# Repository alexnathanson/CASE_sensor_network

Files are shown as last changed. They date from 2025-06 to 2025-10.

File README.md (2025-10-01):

# CASE_sensor_network

https://www.adafruit.com/product/2857

## System Design

Temperature and humidity sensors running on 8 identically configured Raspberry Pi Zero W 2 devices. Each device:
* takes readings every 5 minutes
* stores data locally
* makes data available to other devices on the network through APIs
	* host name is pi*.local where * is a number 1-8
	* Port 5000
	* API endpoints: /api/files, /api/disk, /api/data?date=YYYY-MM-DD

A Windows laptop
* backs up data from each RPi
* collects sensors data from AC
* post aggregated data to cloud database

## Network

When on network, log in to router via a browser with http://tplinkeap.net/ <Br>
See Google Doc for log info.

## Troubleshooting

To find RPi IPs, log in to WAP via browser

## To do

remote access or posting... git?
pscp files to... somewhere?

quality/ health check
* check files exist
* check file sizes
* spot check amount of rows and data validation

fix airtable bug
callibration

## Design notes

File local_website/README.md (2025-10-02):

# Local Website

This directory is for the local website. It will only work on the same local network as the sensors. To run the external website - which pulls less frequent, lower resolution from airtable - see 'external website directory'.

This is a front-end JS only site, the pulls data from the APIs running on the Raspberry Pis.

To run:
* Navigate to the "local_website" directory and run `python -m http.server 8888`
* In a browser, go to http://localhost:8888

## Plots

4 plots
* tempF (ind & abg)
* tempC (ind & abg)
* humidityF (ind & avg)
* Power

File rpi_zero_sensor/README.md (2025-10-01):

# Sensor Network

All RPis should be running:
* dashboard.service

The devices running temperature/ humidity sensors should be running:
* sht31d_logger.service

The device running Kasa should run:
* kasa_logger.service

The device running Airtable (the Kasa rpi in most cases):
* airtable_live.service
* airtable_status.service

Logger collects the data and stores it as a CSV. Dashboard makes the data available via an API. Airtable updates the cloud database.

Note that it is crucial that the host name of each Pi is unique and follows the naming convention. Also, the config file should be updated with the correct number. This should be done automatically if using the installation script. The kasa device is named kasa and the value entered into the config file should be 'kasa'.

Also, each device has a bash script the runs around midnight which pulls the most recent version of the code base from Git.

### Calibration

Calibration values for all sensors is found in the calibration.json file. Updating this file will update the calibration configuration for all sensors. The calibration offset value is applied to the Celsius reading.

## Installation

See <a href='https://github.com/alexnathanson/CASE_sensor_network/blob/main/rpi_zero_sensor/installation.md'>installation doc</a>.

## Dashboards and APIs

### Local Dashboard and APIs

Within the local network (CASE_sensor_network) data from each device can be accessed via their dashboard and APIs. 
All RPi sensors use the same naming convention: pi + #1-8 + .local i.e. pi1.local. The Kasa device can be found at kasa.local.

All APIs and dashboards are available on port 5000

* A dataviz of today's data is available at root: http://pi1.local:5000
* A list of files stored on the device (in json) is available at `api/files`: http://pi1.local:5000/api/files
* To download a specific csv file, use the `api/data` endpoint with the date argument `?date=YYYY-MM-DD`: http://pi1.local:5000/api/data?date=2025-04-6
* To get most recent data (json), use the `api/data` endpoint with the date argument set to now `?date=now`: http://pi1.local:5000/api/data?date=now
* To check disk usage (json), use the `/api/disk` endpoint: http://pi1.local:5000/api/disk

### Local Network Dashboard
When on the local network, live data from all devices can be seen by running the website found in the 'local_website' directory.
* https://github.com/alexnathanson/CASE_sensor_network/blob/main/local%20website/README.md

### External Dashboard

Outside of the local network, data can be check via the Airtable API.

## Airtable

Only 1 RPi in the network updates the airtable. With a free account, we're limited to 1000 API calls a month (~33 calls/ day). 

When both scripts start, they retrieve record IDs (9 calls). Then it updates data as a batch, to minimize calls. The live script makes 1 update every 2 hours, for a total of 21 calls/day. The status script makes 1 update a day, for a total of 9 calls/ day. This requires a combined 30 API calls/ day, for ~930 calls/ month. With a paid account, the resolution can be increased if necessary.

## Troubleshooting

### Status
`sudo systemctl status sht31d_logger.service`

### Logs
`journalctl -u sht31d_logger.service -f`

Stop (temporary) or disable (doesn't start on boot) Service<br>
`sudo systemctl stop sht31d_logger.service`<br>
`sudo systemctl disable sht31d_logger.service`

### Disk Space

Once everything is installed, a 32GB microSD card starts at about 25% full. Check the disk status via the API.

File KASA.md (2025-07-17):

# Kasa

There are 4 Kasa smart plugs in use.

Model: KP125M<br>
Max Load: 15A 1800W

## Setup
You must use the Kasa app to set up the devices and connect them to the network. This requires an account, which is tied to the Kasa username and password. These can be found in the Login & Credentials doc.

In the unlikely event that you need to make changes to the device, you can perform a factory reset and complete the setup instructions on the app. <bold>If you do this, you must update the .env file (and the L&C Google Doc) with the updated credentials.</bold> This file is located in the rpi_zero_sensor directory of each device. You must update all of them.

When setting up a Kasa plug:
* Be sure to use the correct unique name. Devices are named kasa1 to kasa4.
* Make sure they are on the correct wifi network.
* Once set up, in the Kasa app, make sure the default state is set to on.

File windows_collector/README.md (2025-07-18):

# Windows Installation

This scripts is intended to run a local Windows machine to backup data from all sensors.

This is done with the rpi_data_collector.py script.

The best way to automatically run the script is with the Windows Task Scheduler.

Additionally, the local website should be running the this laptop. See <a href='https://github.com/alexnathanson/CASE_sensor_network/tree/main/local_website'>https://github.com/alexnathanson/CASE_sensor_network/tree/main/local_website</a>.

The local website should also be running on this device. Use port 8888 when using Windows Task Scheduler.

## Installation

1) Clone the repository: `git clone https://github.com/alexnathanson/CASE_sensor_network`
2) Create the virtual environment: `python -m venv venv`
3) Activate the virtual environment: `venv\Scripts\activate`
4) Navigate to the windows_collector directory and install requirements:
`pip install -r requirements.txt`
5) Schedule tasks to run via Windows Task Scheduler.

### Windows Task Scheduler
Python scripts can be run via Windows Task Scheduler

General
* Name the task
* Set to run whether user is logged in or not
Triggers
* Set to daily. Around 1am is a good time, because all the sensors will have completed their daily reboot by then.
Actions
* set the script to the python.exe file in your venv
* add the script's full filepath as an argument
* start in specifies the directory it starts from
Conditions
* don't depend on the network connect...
Settings
* run task as soon as possible

## Alternative Automation Method

You can also run the script with NSSM, but this isn't fully tested and is more meant for services not running once a day like this program.

* Download NSSM
* Place nssm.exe in nssm folder in programs directory
* add to environment paths
* open temrinal as admin
	* `nssm install rpi_data_collector`
	* path is path to python.exe in venv
	* startup directory is windows_collector\
	* arg is path to rpi_data_collector.py
	* start service with `nssm start rpi_data_collector`
	* check status with task manager (might just show up as python) or `nssm status rpi_data_collector`

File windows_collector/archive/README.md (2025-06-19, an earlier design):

# Directory for archiving copies of data from sensors

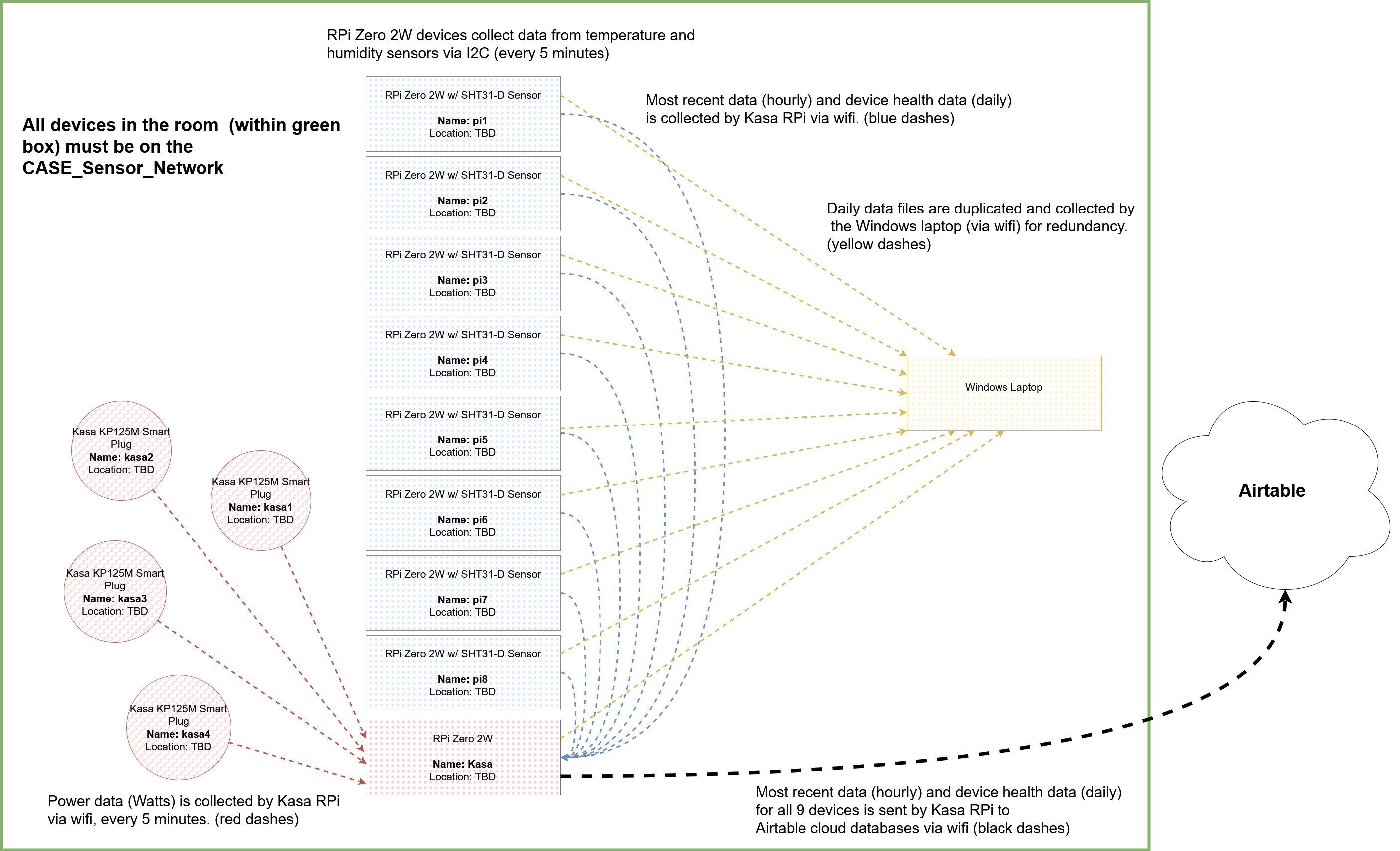
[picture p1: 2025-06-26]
images/sensor-dataflows.jpg

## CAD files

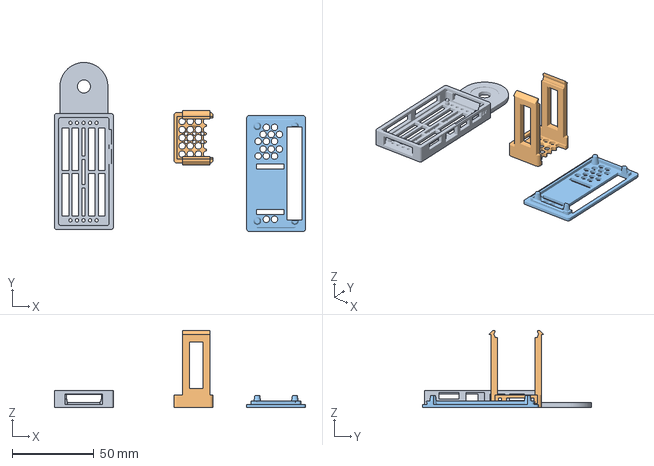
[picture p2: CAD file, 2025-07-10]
rpi_zero_sensor/case/piZwSensor_july10_v2_revC.3mf
153.7 x 103.5 x 47.3 mm

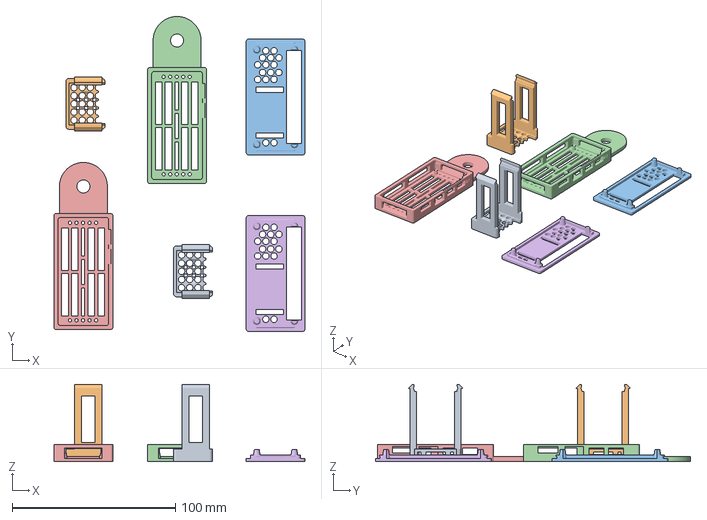
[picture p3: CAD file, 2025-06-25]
rpi_zero_sensor/case/piZwSensor_june24_v2_revBdoubles.3mf
153.7 x 192.9 x 47.3 mm

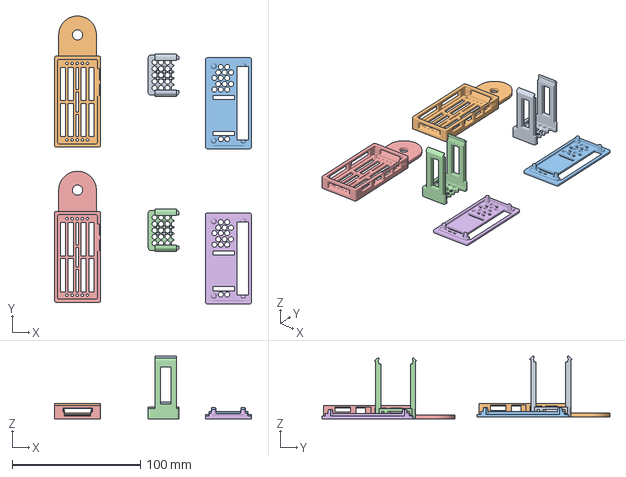
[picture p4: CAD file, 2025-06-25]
rpi_zero_sensor/case/piZwSensor_june24_v2_revB2.3mf
153.7 x 224.6 x 48.8 mm

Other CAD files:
rpi_zero_sensor/case/piZwSensor_june24_v2_revB.3mf
rpi_zero_sensor/case/2857 SHT31-D.3dm

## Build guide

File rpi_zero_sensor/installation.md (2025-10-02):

# RPi Zero W2 Installation

All RPis should be running:
* dashboard.service
The devices running temperature/ humidity sensors should be running:
* sht31d_logger.service
The device running Kasa should runu:
* kasa_logger.service
The device running Airtable (the Kasa rpi in most cases):
* airtable_live.service
* airtable_status.service

Logger collects the data and stores it as a CSV. Dashboard makes the data available via an API. Airtable updates the cloud database.

Note that it is crucial that the host name of each Pi is unique and follows the naming convention. Also, the config file should be updated with the correct number. The kasa device is named kasa and the value entered into the config file should be 'kasa'.

## OS and Software Installation

### Pi Imager Settings

It is crucial that the host name of each Pi is unique and follows the naming convention, pi + integer. There are 8 sensors, so the range of numbers is 1-8.<br>
hostname: pi[#1-8].local

The hostname for the device collecting Kasa data is kasa.local

See credentials doc for username, password, and network setting to use.

### Pi Setup
`sudo apt-get update`

`sudo apt-get upgrade`

`sudo raspi-config`
* Enable I2C
* Don't overlay file system
* Localization
	* enable US.UTF-8 (optionally, removing GB will free up a little space)
	* set timezone to NY
	* set WLAN to US
* Expand filesystem

Clone repository<br>
`git clone https://github.com/alexnathanson/CASE_sensor_network.git`

Create .env file if accessing either the Kasa or Airtable APIs.
* In rpi_zero_sensor directory: `sudo nano /home/case/CASE_sensor_network/rpi_zero_sensor/.env`
* Add the Airtable API key and Kasa user credentials, with the variable names shown below. See credentials doc for info.
	* `AIRTABLE=**************`
	* `KASA_UN=**************`
	* `KASA_PW=**************`

Run automated installer script (most recent version isn't tested):<br>
`sudo bash /home/case/CASE_sensor_network/rpi_zero_sensor/utilities/installer.sh`

Run the September 16th update - this includes some stuff so that the device reboots itself automatically if it stalls
`sudo bash /home/case/CASE_sensor_network/rpi_zero_sensor/utilities/update_sept16.sh`

After install, update the file start date and location in the config file as necessary.

Add this line to the bottom of the crontab file to pull newest version and restart nightly. (It also restarts ~3am, which is kind of redundant)
* `crontab -e`
* `10 0 * * * sudo bash /home/case/CASE_sensor_network/rpi_zero_sensor/utilities/simple-update.sh > /home/case/CASE_sensor_network/rpi_zero_sensor/utilities/simple-update.log 2>&1`

### Steps included in automated installation via utilities/installer.sh
The following code does not need to be done manually, because it is included in script.

Some things that should be done manually after installation:
* change start date in config file
* run status checks

#### Setup Directories

Create data directory and assign ownership<br>
`mkdir /home/case/data`<br>
`sudo chown case:case /home/case/data`

Copy config and set sensor number<br>
`sudo cp /home/case/CASE_sensor_network/rpi_zero_sensor/config_template.json /home/case/CASE_sensor_network/rpi_zero_sensor/config.json`<br>
`sudo nano /home/case/CASE_sensor_network/rpi_zero_sensor/config.json`

Create venv in user directory<br>
`cd /home/case<br>`<br>
`python -m venv venv`

Activate venv<br>
`source venv/bin/activate`

#### Install libraries

Install from requirements.txt<br>
`pip install -r requirements.txt`

If that fails, install manually via pip:

* SHT31-D sensor library https://github.com/adafruit/Adafruit_CircuitPython_SHT31D
	* `pip install adafruit-circuitpython-sht31d`
* `pip install pandas`

#### Automate

<p>
	Depending on the device, different services are used (see above). Follow same pattern for each one as needed:
</p>

Make script executable<br>
`chmod +x /home/case/CASE_sensor_network/rpi_zero_sensor/sht31d_logger.py`

Copy service file<br>
`sudo cp sh31d_logger.service /etc/systemd/system/sht31d_logger.service`

Reload and enable<br>
`sudo systemctl daemon-reexec`<br>
`sudo systemctl daemon-reload`<br>
`sudo systemctl enable sht31d_logger.service`<br>
`sudo systemctl start sht31d_logger.service`

Dashboard Automation:<br>
`chmod +x /home/case/CASE_sensor_network/rpi_zero_sensor/sht31d_dashboard.py`<br>
`sudo cp sh31d_dashboard.service /etc/systemd/system/sht31d_dashboard.service`<br>
`sudo systemctl daemon-reexec`<br>
`sudo systemctl daemon-reload`<br>
`sudo systemctl enable sht31d_dashboard.service`<br>
`sudo systemctl start sht31d_dashboard.service`

Set daily reboot at 3am (run manually - not installed automatically)<br>
`sudo crontab -e`<br>
Add this line at the bottom of the file `0 3 * * * /sbin/reboot`

#### To confirm successful installation

After running automation installer, check if they are running<br>
`sudo systemctl status sht31d_logger.service`<br>
`sudo systemctl status sht31d_dashboard.service`

## SHT31-D Sensor Wiring


## Troubleshooting

If for some reason, the Kasa library wasn't working when install with pip, so it needed to be installed from git.<br>
`git clone https://github.com/python-kasa/python-kasa.git`<br>
`cd python-kasa/`<br>
`pip install .`

### Logs
`journalctl -u sht31d_logger.service -f`

Stop (temporary) or disable (doesn't start on boot) Service<br>
`sudo systemctl stop sht31d_logger.service`<br>
`sudo systemctl disable sht31d_logger.service`

### Disk Space

Once everything is installed, a 32GB microSD card starts at about 25% full. Check the disk status via the API.

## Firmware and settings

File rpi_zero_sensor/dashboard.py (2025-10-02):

from flask import Flask, render_template_string, request, send_file, abort, jsonify
from flask_cors import CORS
import csv
import datetime
from datetime import timedelta, date
import os 
import glob
import json
import pandas as pd
import logging
import subprocess
from typing import Any, Dict, List
#import shutil
#import re

# ------------------ Config ------------------ #
#logging.basicConfig(level=logging.INFO)
logging.basicConfig(filename='/home/case/CASE_sensor_network/rpi_zero_sensor/logs/dashboard.log',format='%(asctime)s - %(levelname)-8s [%(filename)s:%(lineno)d] %(message)s',datefmt='%Y-%m-%d %H:%M:%S',level=logging.DEBUG)

with open("/home/case/CASE_sensor_network/rpi_zero_sensor/config.json") as f:
    config = json.load(f)

deviceNum = config["sensor"]["number"]
logging.debug(f'device number: {deviceNum}')

startDate = config["sensor"]["start_date"]
logging.debug(f'start date: {startDate}')

location = config["sensor"]["location"]

app = Flask(__name__)

# CORS is enabled for all routes. This simplifies the frontend visualization,
# but could be removed for security purposes or to more easily enforce throttling without straining the Pi Zeros.
CORS(app)  

filePath = '/home/case/data/'
if deviceNum == 'kasa':
    filePrefix = 'kasa_'
else:
    filePrefix = 'sensor' + str(deviceNum) + '_'
logging.debug(f'file prefix: {filePrefix}')

HTML = """
<!DOCTYPE html>
<html>
<head>
    <title>Pi Sensor Dashboard</title>
    <meta http-equiv="refresh" content="60" />
    <style>
        body { font-family: sans-serif; margin: 2em; }
        table { border-collapse: collapse; }
        td, th { padding: 0.5em; border: 1px solid #ccc; }
    </style>
</head>
<body>
    <h1>Pi Zero W2 SHT31D Sensor Dashboard</h1>
    <p>
        Project documentation can be found at <a href="https://github.com/alexnathanson/CASE_sensor_network/" target="_blank">https://github.com/alexnathanson/CASE_sensor_network/</a>
    </p>
    <h2>Retrieving Data</h2>
    <p>
        The best ways to retrieve sensor data are manually <a href="/download">on this page</a> or programatically via the API. Additional methods are described in the Github repository.
    </p>
    <p>
        There are 4 API endpoints - files, data, and health.
        <ul>
            <li>View file list with <a href='/api/files' target="_blank">/api/files</a></li>
            <li>View most recently collected data with <a href='/api/data?date=now' target="_blank">/api/data?date=now</a></li>
            <li>Download CSV file with /api/data?date=YYYY-MM-DD (Replace YYYY-MM-DD with date as shown in file list.)</li>
            <li>View Raspberry Pi health status with <a href='/api/health' target="_blank">/api/health</a></li>
            <li>View location of device (as specified in the config file) <a href='/api/location' target="_blank">/api/location</a></li>
        </ul>
    </p>
    <h2>Today's Data</h2>
    <table>
        <tr><th>Timestamp</th><th>Temp (°C)</th><th>Temp (°C calibrated)</th><th>Temp (°F)</th><th>Humidity (%)</th></tr>
        {% for row in data %}
        <tr>
            <td>{{ row[0] }}</td>
            <td>{{ row[1] }}</td>
            <td>{{ row[2] }}</td>
            <td>{{ row[3] }}</td>
            <td>{{ row[4] }}</td>
        </tr>
        {% endfor %}
    </table>
    <p>Auto-refreshes every 60 seconds</p>
</body>
</html>
"""

DOWNLOAD = """
<!DOCTYPE html>
<html>
<head>
    <title>Pi Sensor Dashboard</title>
    <meta http-equiv="refresh" content="60" />
    <style>
        body { font-family: sans-serif; margin: 2em; }
        table { border-collapse: collapse; }
        td, th { padding: 0.5em; border: 1px solid #ccc; }
    </style>
</head>
<body>
    <h1>Pi Zero W2 SHT31D Sensor Dashboard</h1>
    <p>
        <a href='/'>home</a>
    </p>
    <h2>Available CSV Files to Download</h2>
    <table>
        <tr><th>Name</th></tr>
        {% for row in data %}
        <tr>
            <td><a href="/api/data?date={{ row[0] }}" target="_blank">{{ row[0] }}</a></td>
        </tr>
        {% endfor %}
    </table>
</body>
</html>
"""

if deviceNum == 'kasa':
    HTML = HTML.replace("<th>Temp (°C)</th><th>Temp (°C calibrated)</th><th>Temp (°F)</th><th>Humidity (%)</th>","<th>Kasa1 W</th><th>Kasa2 W</th><th>Kasa3 W</th><th>Kasa4 W</th>")
    #HTML = HTML.replace("<td>{{ row[3] }}</td>","<td>{{ row[3] }}</td><td>{{ row[4] }}</td>") #no longer needed with the addition of the calibration column

@app.route("/")
def index():
    fileName = filePath + filePrefix +str(datetime.date.today())+'.csv'
    with open(fileName, newline='') as f:
        reader = csv.reader(f)
        next(reader)  # skip header
        rows = list(reader)#[-10:]  # last 10 readings
    return render_template_string(HTML, data=rows)


@app.route("/download")
def download():
    # Get all CSV files in the data/ directory
    file_pattern = os.path.join(filePath, f"{filePrefix}*.csv")
    files = sorted(glob.glob(file_pattern))

    # Return just the filenames (without full paths)
    rows = [[os.path.basename(f).replace('.csv','').split('_')[1]] for f in files]

    return render_template_string(DOWNLOAD, data=rows)

@app.route("/api/data")
def get_csv_for_date():
    date = request.args.get("date")
    if not date:
        return "Please provide a date using ?date=YYYY-MM-DD or ?date=now for most recent data", 400

    if date == 'now':
        pass
        try:
            fileName = filePrefix +str(datetime.date.today())+'.csv'
            fullFilePath = filePath + fileName #os.path.join(fileName)
            df = pd.read_csv(fullFilePath)  # Update path as needed

            if df.empty:
                return jsonify({'error': 'CSV is empty'}), 404

            last_row = df.iloc[-1].to_dict()
            return jsonify(last_row)
        except FileNotFoundError:
            return jsonify({'error': 'CSV file not found'}), 404
        except Exception as e:
            return jsonify({'error': str(e)}), 500
    else:
        fileName = filePrefix +date+'.csv'
        fullFilePath = filePath + fileName #os.path.join(fileName)

        if not os.path.exists(fullFilePath):
            return f"No data found for {date}", 404

        return send_file(fullFilePath, as_attachment=True, download_name=fileName)

@app.route("/api/files")
def list_csv_files():
    #fileName = filePrefix +str(datetime.date.today())+'.csv'

    # Get all CSV files in the data/ directory
    file_pattern = os.path.join(filePath, f"{filePrefix}*.csv")
    files = sorted(glob.glob(file_pattern))

    # Return just the filenames (without full paths)
    filenames = [os.path.basename(f) for f in files]

    return jsonify(filenames)

@app.route("/api/location")
def getLocation():
    return location

def parse_disk_usage():
    stat = os.statvfs("/")

    total = stat.f_frsize * stat.f_blocks      # Total space
    free = stat.f_frsize * stat.f_bavail       # Available space
    used = total - free

    total_mb = total // (1024 * 1024)
    used_mb = used // (1024 * 1024)
    free_mb = free // (1024 * 1024)
    percent_used = round((used / total) * 100, 1)

    diskDict =  {
        "total_mb": total_mb,
        "used_mb": used_mb,
        "free_mb": free_mb,
        "percent_used": percent_used
    }

    return diskDict

@app.route("/api/disk")
def get_disk_usage():
    return jsonify(parse_disk_usage())

def run_command(cmd):
    try:
        result = subprocess.run(cmd, shell=True, capture_output=True, text=True)
        return result.stdout.strip() if result.returncode == 0 else f"Error: {result.stderr.strip()}"
    except Exception as e:
        return f"Exception: {str(e)}"

def parse_timestamp(filename, startDate:str, time_format:str="%Y-%m-%d",):
    fileDate = filename.split("_")[-1].replace(".csv","")
    if fileDate and (fileDate != str(datetime.date.today())): #ignore today's file
        formattedFileDate = datetime.datetime.strptime(fileDate, time_format)
        if formattedFileDate > datetime.datetime.strptime(startDate, time_format): #filter by start date
            return formattedFileDate
        return None
    return None

def check_file_size_uniformity(folder_path:str, tolerance_ratio:float=0.2)->Dict:
    interval_minutes=60*60*24
    file_data=[]
    for f in os.listdir(folder_path):
        try:
            full_path = os.path.join(folder_path, f)
            if os.path.isfile(full_path):
                ts = parse_timestamp(f,startDate)
                if ts:
                    size = os.path.getsize(full_path)
                    file_data.append((f, ts, size))
        except Exception as e:
            logging.error(f'{e}')

    if not file_data:
        return "No timestamped files found in directory."

    # Sort by timestamp
    file_data.sort(key=lambda x: x[1])
    sizes = [s for _, _, s in file_data]
    avg = sum(sizes) / len(sizes)
    lower_bound = avg * (1 - tolerance_ratio)
    upper_bound = avg * (1 + tolerance_ratio)

    outliers = [(f, s) for f, _, s in file_data if s < lower_bound or s > upper_bound]

    # Find missing timestamps
    expected_ts = []
    current = file_data[0][1]
    end = file_data[-1][1]
    while current <= end:
        expected_ts.append(current)
        current += timedelta(minutes=interval_minutes)

    existing_ts = set(ts for _, ts, _ in file_data)
    missing_ts = [dt for dt in expected_ts if dt not in existing_ts]

    return {
        "total_files": len(file_data),
        "startDate" : startDate,
        "average_size_bytes": avg,
        "outliers": outliers,
        "missing_timestamps": [dt.strftime("%Y-%m-%d %H:%M") for dt in missing_ts],
        "status": "OK" if not outliers and not missing_ts else "WARNING: Issues found"
    }


def check_mmc_errors():
    dmesg_output = run_command("dmesg | grep mmc")

    error_keywords = ["error", "fail", "timeout", "crc", "interrupt", "reset", "re-init"]
    warnings = [
        line for line in dmesg_output.splitlines()
        if any(kw.lower() in line.lower() for kw in error_keywords)
    ]

    return warnings

def getServiceStatus(service):
    try:
        result = subprocess.run(
            ['systemctl', 'is-active', service],
            stdout=subprocess.PIPE,
            stderr=subprocess.PIPE,
            text=True
        )
        return result.stdout.strip()
    except Exception as e:
        return f'Error: {str(e)}'

@app.route("/api/health")
def health_check():
    # any run_command can also be entered manually in terminal
    dt = datetime.datetime.now()

    try:
        cpu_tempC = float(run_command("vcgencmd measure_temp").replace('temp=','').replace("\'C",""))
    except Exception as e:
        cpu_tempC = f"error: {str(e)}"

    try:
        uptime = run_command("uptime").split(',')[0]
    except Exception as e:
        uptime = f"error: {str(e)}"

    try:
        availMem = int(run_command("free -h").split('\n')[1].split()[-1].replace('Mi',''))
        memStatus = 'OK'
        if availMem < 50:
            memStatus = 'VERY LOW'
        elif availMem < 100:
            memStatus = 'LOW'
        memoryUsage = {'available memory':f'{availMem}Mi','status':memStatus}
    except Exception as e:
        memoryUsage = f"error: {str(e)}"

    try:
        diskUsage = parse_disk_usage()#run_command("df -h")
    except Exception as e:
        diskUsage = f"error: {str(e)}"

    try:
        throttled = run_command("vcgencmd get_throttled")
        if "0x0" in throttled:
            throttled = "OK"
        else:
            throttled = "Power supply issue or undervoltage!"
        powerIssues = throttled
    except Exception as e:
        powerIssues = f"error: {str(e)}"

    try:
        sdCardErrors = check_mmc_errors()# run_command("dmesg | grep mmc")
    except Exception as e:
        sdCardErrors = f"error: {str(e)}"

    try:
        fileStatus = check_file_size_uniformity("/home/case/data")
    except Exception as e:
        fileStatus = f"error: {str(e)}"

    try:
        serviceList = ['airtable_live','airtable_status','dashboard','kasa_logger','sht31d_logger']
        serviceDict = {}
        for s in serviceList:
            serviceDict[s] = getServiceStatus(s)
    except Exception as e:
        serviceDict = f"error:{str(e)}"

    try:
        commit = subprocess.check_output(
            ["git", "rev-parse", "--short", "HEAD"],
            cwd='/home/case/CASE_sensor_network').decode().strip()
    except Exception as e:
        commit = f"errpr{str(e)}"

    try:
        branch = subprocess.check_output(
            ["git", "rev-parse", "--abbrev-ref", "HEAD"],
            cwd='/home/case/CASE_sensor_network').decode().strip()
    except Exception as e:
        branch = f"errpr{str(e)}"

    # liveLogFile='/home/case/CASE_sensor_network/rpi_zero_sensor/airtable_live.log'
    # statusLogFile='/home/case/CASE_sensor_network/rpi_zero_sensor/airtable_status.log'

    # try:
    #     # past 2 dates in format (YYYY-MM-DD)
    #     logDates = []
    #     duration = 2
    #     for d in range(duration):
    #         dt_log = date.today()-timedelta(days=duration-d-1)
    #         logDates.append(dt_log.strftime("%Y-%m-%d"))
    #     logging.info(f'dates:{logDates}')

    #     # get live logs
    #     try:
    #         liveLog = []
    #         with open(liveLogFile, "r", encoding="utf-8") as f:
    #             for line in f:
    #                 for d in logDates:
    #                     if d in line and ("ERROR" in line or "CRITICAL" in line):
    #                         liveLog.append(line.strip())
    #     except Exception as e:
    #         liveLog = f"Error getting live log: {e}"

    #     # get status logs
    #     try:
    #         statusLog = []
    #         with open(statusLogFile, "r", encoding="utf-8") as f:
    #             for line in f:
    #                 for d in logDates:
    #                     if d in line and ("ERROR" in line or "CRITICAL" in line):
    #                         statusLog.append(line.strip())
    #     except Exception as e:
    #         statusLog = f"Error getting status log: {e}"
    # except Exception as e:
    #     liveLog = f"Error getting all logs: {e}"
    #     statusLog = liveLog

    return jsonify({
        "datetime": dt.strftime("%Y-%m-%d %H:%M:%S"),
        "cpu_tempC": cpu_tempC,
        "uptime": uptime,
        "memoryUsage": memoryUsage,
        "diskUsage" : diskUsage,
        "powerIssues" : powerIssues,
        "sdCardErrors" : sdCardErrors,
        "fileStatus":fileStatus,
        "services":serviceDict,
        "branch":branch,
        "commit":commit#,
        # "liveLog":liveLog,
        # "statusLog":statusLog
    })

if __name__ == "__main__":
    app.run(host="0.0.0.0", port=5000, debug=False)

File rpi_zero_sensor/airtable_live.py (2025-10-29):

import os
import datetime
import json
from dotenv import load_dotenv
import asyncio
import logging
#from logging.handlers import RotatingFileHandler
import requests
from typing import Any, Dict, Optional, List
from airtable import Airtable

# ------------------ Config ------------------ #
#logging.basicConfig(level=logging.DEBUG)
logDT = datetime.datetime.now().strftime("%Y-%m-%d")
logging.basicConfig(filename=f'/home/case/CASE_sensor_network/rpi_zero_sensor/logs/airtable_live_{logDT}.log',format='%(asctime)s - %(levelname)-8s [%(filename)s:%(lineno)d] %(message)s',datefmt='%Y-%m-%d %H:%M:%S',level=logging.INFO)

load_dotenv()
key = os.getenv('AIRTABLE')
if not key:
    logger.error("Missing AIRTABLE in environment.")
    raise EnvironmentError("Missing Kasa credentials")

# if true collect Kasa data
#includeKasa = True

try:
    with open("/home/case/CASE_sensor_network/rpi_zero_sensor/config.json") as f:
        config = json.load(f)

    deviceNum = config["sensor"]["number"]
except Exception as e:
    logging.error(e)

# mode: 1 = only individual data; 8 = all data
MODE = 8

FREQ_SECONDS = 60 * 20 #updates every half an hour

async def send_get_request(url,type:str,backoff:int=1,timeout=1) -> Any:
    """Send GET request to the IP."""

    # get own data
    max_tries = 3
    for attempt in range(max_tries):
        logging.debug(f'Attempt #{attempt+1}')
        try:
            response = requests.get(f"{url}", timeout=timeout)
            response.raise_for_status()
            if type == 'json':
                res = response.json()
            elif type == 'text':
                res = response.text
            else:
                res = response.status_code
            break
        except Exception as e:
            logging.error(f'{e}')
            if attempt == max_tries-1: # try up to 3 times
                res = {}
                logging.debug('FAILED!!!')
            else:
                logging.debug('SLEEEEEEEEEEEEEEEEEPING')
                await asyncio.sleep(1+(int(backoff)* int(attempt)))

    return res

async def main():
    AT = Airtable(key,'live')

    # get names
    for n in range(8):
        AT.sensors[f'sensor{n+1}']={"id":"","data":""}

    AT.sensors['kasa']={"id":"","data":""}

    logging.debug(AT.sensors)

    AT.names = list(AT.sensors.keys())

    while True:

        logging.debug('Starting loop!')

        # get record IDs
        try:
            await AT.getRecordID(AT.names)
            logging.debug(AT.sensors)
        except Exception as e:
            logging.error(f'Error getting airtable IDs: {e}')

        # sensor data
        for n in range(8):
            url = f"http://pi{n+1}.local:5000/api/data?date=now"
            AT.sensors[AT.names[n]]['data']= await send_get_request(url,'json')

            # if no results, wait 5 seconds and try again in a few minutes
            if AT.sensors[AT.names[n]]['data'] == {}:
                await asyncio.sleep(5)
                AT.sensors[AT.names[n]]['data'] = await send_get_request(url,'json',3)


        # kasa data
        url = f"http://kasa.local:5000/api/data?date=now"
        AT.sensors['kasa']['data']=await send_get_request(url,'json')

        # if no results, wait 5 seconds and try again in a few minutes
        if AT.sensors['kasa']['data'] == {}:
            await asyncio.sleep(5)
            AT.sensors['kasa']['data'] = await send_get_request(url,'json',3)


        logging.debug(AT.sensors)
        try:
            await AT.updateBatch(AT.names,AT.sensors)
        except Exception as e:
            logging.error(e)

        logging.debug(f'Sleeping for {FREQ_SECONDS/60} minutes.')
        await asyncio.sleep(FREQ_SECONDS)

if __name__ == "__main__":
    try:
        asyncio.run(main())
    except Exception as e:
        logging.critical(f"Main loop crashed: {e}")

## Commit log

2025-04-08 fixed file path api and live data enabled
    [pi1_2025-04-07.csv]
2025-06-19 kasa logger
    [kasa_2025-06-19.csv]
2025-06-19 removed kasa archive
    [kasa_2025-06-19.csv]
2025-06-20 airtable test
    [kasa_2025-06-19.csv]
2025-06-21 case rev4
2025-06-23 reboot prompt
    [piZwSensor_june23_revD.3mf]
2025-06-24 html dashboard
    [piZwSensor_june24_revF.3mf, piZwSensor_june24_revFb.3mf]
2025-06-24 filter by start date
2025-06-25 at test
    [piZwSensor_june24_v2_revB.3mf]
2025-06-25 airtable class
    [piZwSensor_june24_v2_revB2.3mf, piZwSensor_june24_v2_revBdoubles.3mf]
2025-06-25 rem old rhino
    [piZwSensor_june23_revD.3mf, piZwSensor_june23_revE.3mf, piZwSensor_june24_revF.3mf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]
2025-07-15 fixed dumb dashboard error
    [dashboard.py]
2025-07-17 download file page
    [kasa_2025-07-16.csv, pi1_2025-07-16.csv, pi2_2025-07-16.csv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]
2025-08-20 sensor num not needed for kasa
2025-09-30 device name column added
2025-10-02 show calibrated data
2025-10-02 display calibration
